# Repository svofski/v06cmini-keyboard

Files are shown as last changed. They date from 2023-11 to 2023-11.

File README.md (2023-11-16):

# A miniature keyboard for Vector-06c

The keyboard is a miniature full-functioning replica of Vector-06c keyboard. Its dimensions are 150x55mm. 
It can be connected as a replacement keyboard to the real Vector-06c, or it can be used as a USB HID keyboard with a Vector-06c emulator or FPGA implementation.
It can also be connected to v06c-esp vector-06c-mini.

The design files comprise 3 parts. 

 1. [Key caps](blender) A high resolution mesh with legend engraving designed in blender
 2. [Bottom PCB](kicad/v06ckeyboard) carries the switches and an optional Pi Pico for connectivity
 3. [Top PCB](kicad/v06ckeyboard) a frame that holds the keycaps in place

This keyboard is very small indeed.

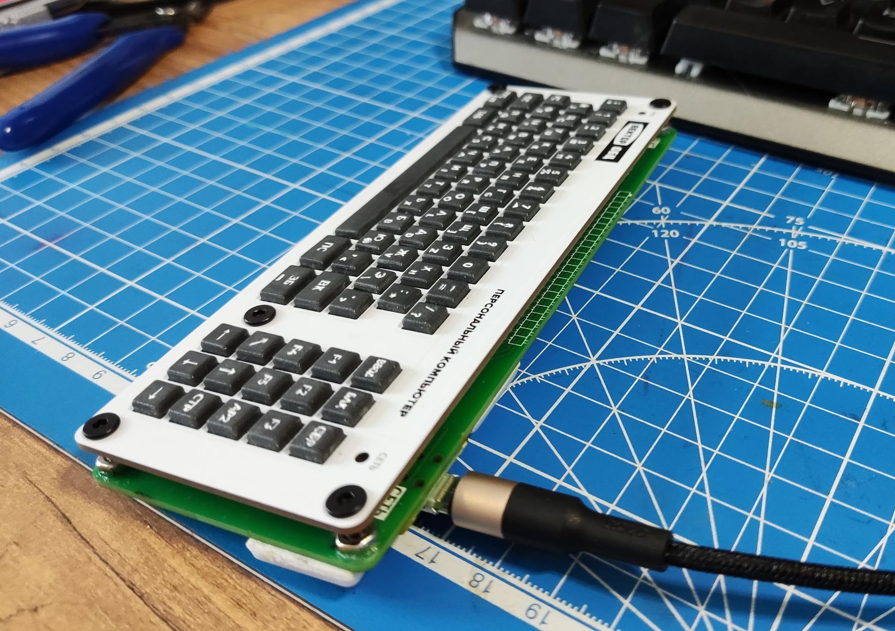
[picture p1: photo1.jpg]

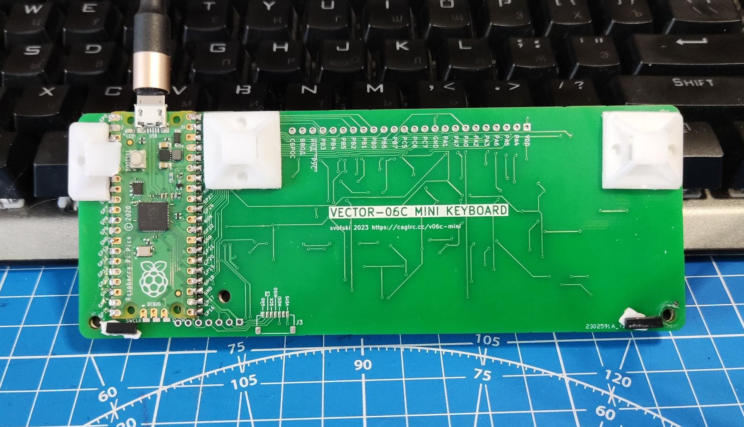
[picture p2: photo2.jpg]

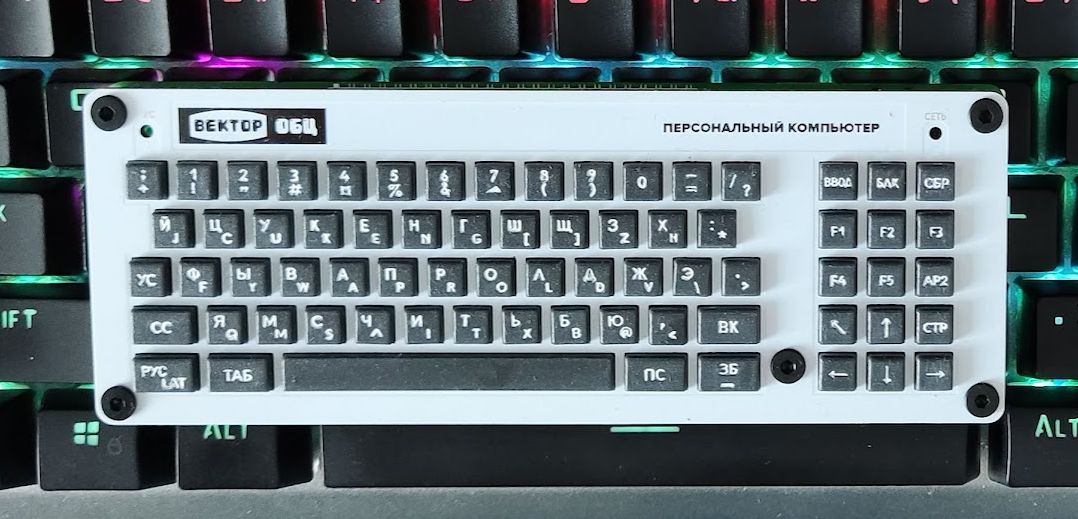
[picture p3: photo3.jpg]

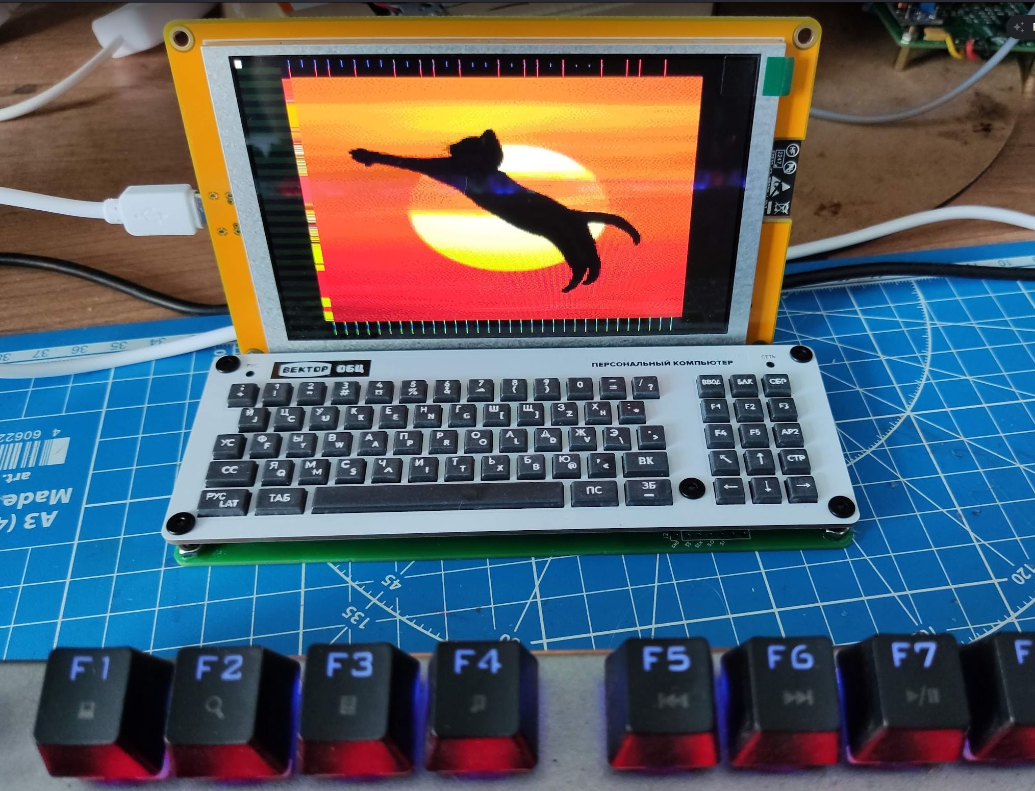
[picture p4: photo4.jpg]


## Firmware

### spislave

[spislave](firmware/spislave) is the main intended use with [v06x-mini](https://github.com/svofski/v06x-tiny).

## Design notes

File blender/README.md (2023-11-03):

# Keycaps design files

keyboard1.blend is the assembly model and keycaps model

Exported .stl is in production files.

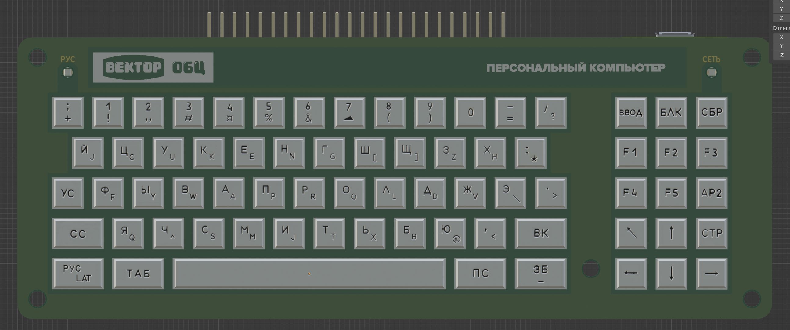
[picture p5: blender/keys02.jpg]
keys02

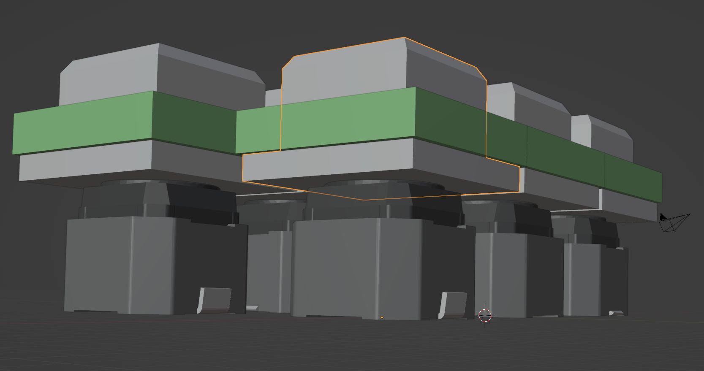
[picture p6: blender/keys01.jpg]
keys01


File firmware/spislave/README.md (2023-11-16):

# v06c-mini keyboard spislave

This is the main mode of this keyboard.
It's an SPI slave for v06x-mini emulator running on esp32-s3.

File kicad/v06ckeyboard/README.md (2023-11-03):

# vector-06c-mini keyboard PCBs

Main PCB and keycaps frame.

Explore using [kicanvas](https://kicanvas.org/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).

[PDF schematic](/kicad/v06ckeyboard/v06c-mini-keyboard.pdf)

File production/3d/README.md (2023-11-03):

[keyboard1.zip](keyboard1.zip) keyboard1.stl suitable for 3D printing

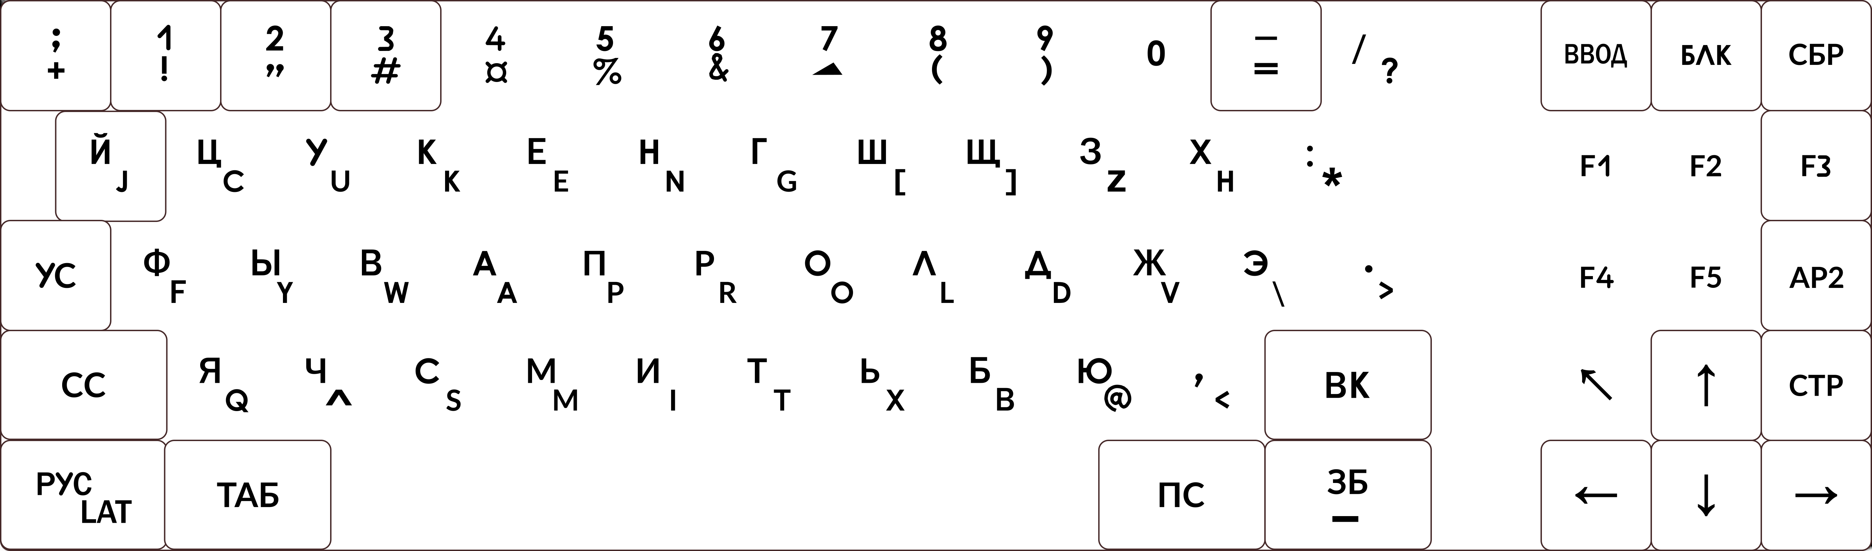
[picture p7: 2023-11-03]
blender/v06c-bump2.png

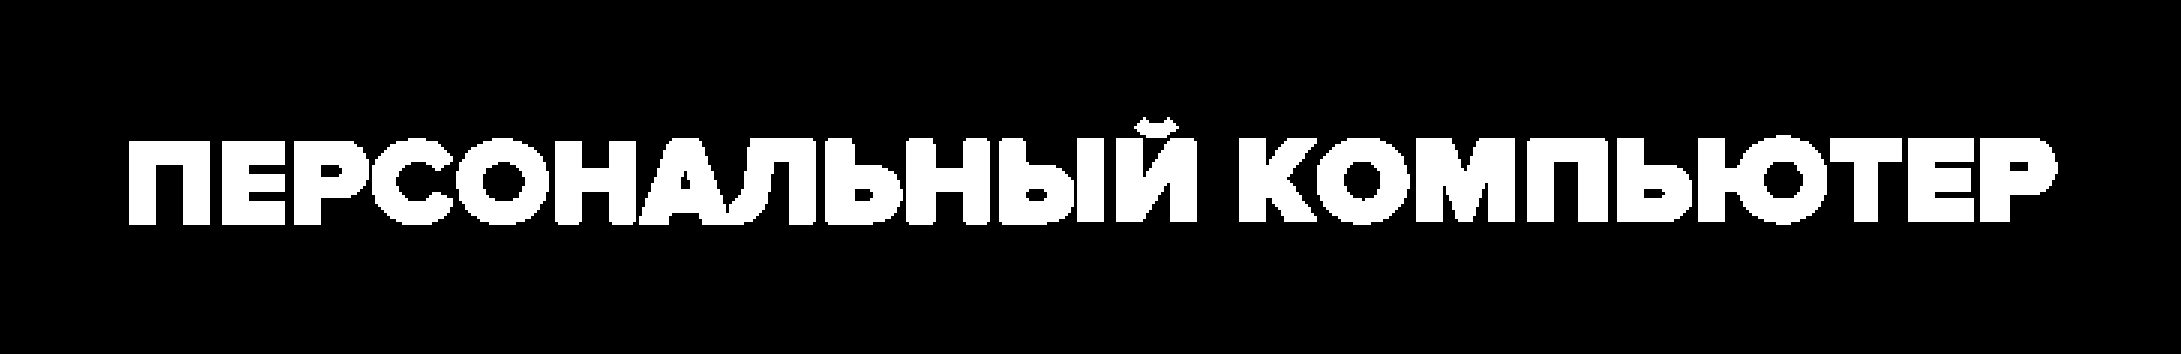
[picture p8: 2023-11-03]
blender/personal.png

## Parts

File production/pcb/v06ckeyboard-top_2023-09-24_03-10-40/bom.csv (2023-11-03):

Designator | Footprint | Quantity | Value | LCSC Part #
H1, H2_3, H2_2, H2, H3, H4, H5 | MountingHole_3.2mm_M3 | 7 | MountingHole
SW100_ВВОД1, SW101_СБР1, SW102_БЛК1, SW104_УС1, SW10_1, SW11_9, SW12_А1, SW13_И1, SW14_Я1, SW15_Ы1, SW16_СТР1, SW18_2, SW19_:1, SW20_Б1, SW21_Й1, SW22_Р1, SW23_З1, SW24_AP2, SW26_3, SW27_;1, SW28_Ц1, SW29_К1, SW2_0, SW30_С1, SW31_Ш1, SW32_F1, SW33_LT1, SW34_4, SW35_,<1, SW36_Д1, SW37_Л1, SW38_Т1, SW39_Э1, SW3_8, SW40_F2, SW41_UP1, SW42_5, SW43_-=1, SW44_E1, SW45_М1, SW46_У1, SW47_Щ1, SW48_F3, SW49_RT1, SW4_Ю1, SW50_6, SW51_.>1, SW52_Ф1, SW53_Н1, SW54_Ж1, SW55_Ч1, SW56_F4, SW57_DN1, SW58_7, SW59_/1, SW5_Х1, SW60_Г1, SW61_О1, SW62_В1, SW64_F5, SW6_П1, SW7_Ь1, SW8_HOME1 | SKPM_Top_Hole | 63 | SKPMAME010 | C115348
SW103_СС1, SW105_РУС/LAT1, SW17_ВК1, SW1_ТАБ1, SW25_ЗБ1, SW9_ПС1 | SKPM_Top_Hole_1.5u | 6 | SKPMAME010 | C115348
SW63_SPC1 | SKPM_Top_Hole_7u | 1 | SKPMAME010 | C115348

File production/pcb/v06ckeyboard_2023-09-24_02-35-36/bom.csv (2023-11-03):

Designator | Footprint | Quantity | Value | LCSC Part #
D1, D2, D3, D4, D5, D6, D7, D8, D9 | D_SOD-323 | 9 | 1N4148WS | C2128
D10 | 0805 | 1 | POWER
D11 | 0805 | 1 | РУС/LAT
H1, H2, H3, H4, H5 | MountingHole_3.2mm_M3 | 5 | MountingHole
J1 | PinHeader_1x24_P2.54mm_Horizontal | 1 | Conn_01x24
J2 | PinHeader_1x07_P2.54mm_Vertical | 1 | SH1.0-7
J3 | JST_SH_SM07B-SRSS-TB_1x07-1MP_P1.00mm_Horizontal | 1 | SH1.0-7
R1, R2, R3, R4, R5, R6, R7, R8 | 0603 | 8 | 2K
R10, R11, R12, R13, R14, R15, R16, R19, R20, R21, R9 | 0603 | 11 | 10K
R17, R18 | 0603 | 2 | 1K
R22, R23 | 0603 | 2 | 430
SW100_ВВОД1, SW101_СБР1, SW102_БЛК1, SW103_СС1, SW104_УС1, SW105_РУС/LAT1, SW10_1, SW11_9, SW12_А1, SW13_И1, SW14_Я1, SW15_Ы1, SW16_СТР1, SW17_ВК1, SW18_2, SW19_:1, SW1_ТАБ1, SW20_Б1, SW21_Й1, SW22_Р1, SW23_З1, SW24_AP2, SW25_ЗБ1, SW26_3, SW27_;1, SW28_Ц1, SW29_К1, SW2_0, SW30_С1, SW31_Ш1, SW32_F1, SW33_LT1, SW34_4, SW35, SW36_Д1, SW37_Л1, SW38_Т1, SW39_Э1, SW3_8, SW40_F2, SW41_UP1, SW42_5, SW43_-=1, SW44_E1, SW45_М1, SW46_У1, SW47_Щ1, SW48_F3, SW49_RT1, SW4_Ю1, SW50_6, SW51, SW52_Ф1, SW53_Н1, SW54_Ж1, SW55_Ч1, SW56_F4, SW57_DN1, SW58_7, SW59_/1, SW5_Х1, SW60_Г1, SW61_О1, SW62_В1, SW63_SPC1, SW63_SPC2, SW64_F5, SW6_П1, SW7_Ь1, SW8_HOME1, SW9_ПС1 | SKPM | 71 | SKPMAME010 | C115348
U1 | RPi_Pico_SMD_TH | 1 | Pico

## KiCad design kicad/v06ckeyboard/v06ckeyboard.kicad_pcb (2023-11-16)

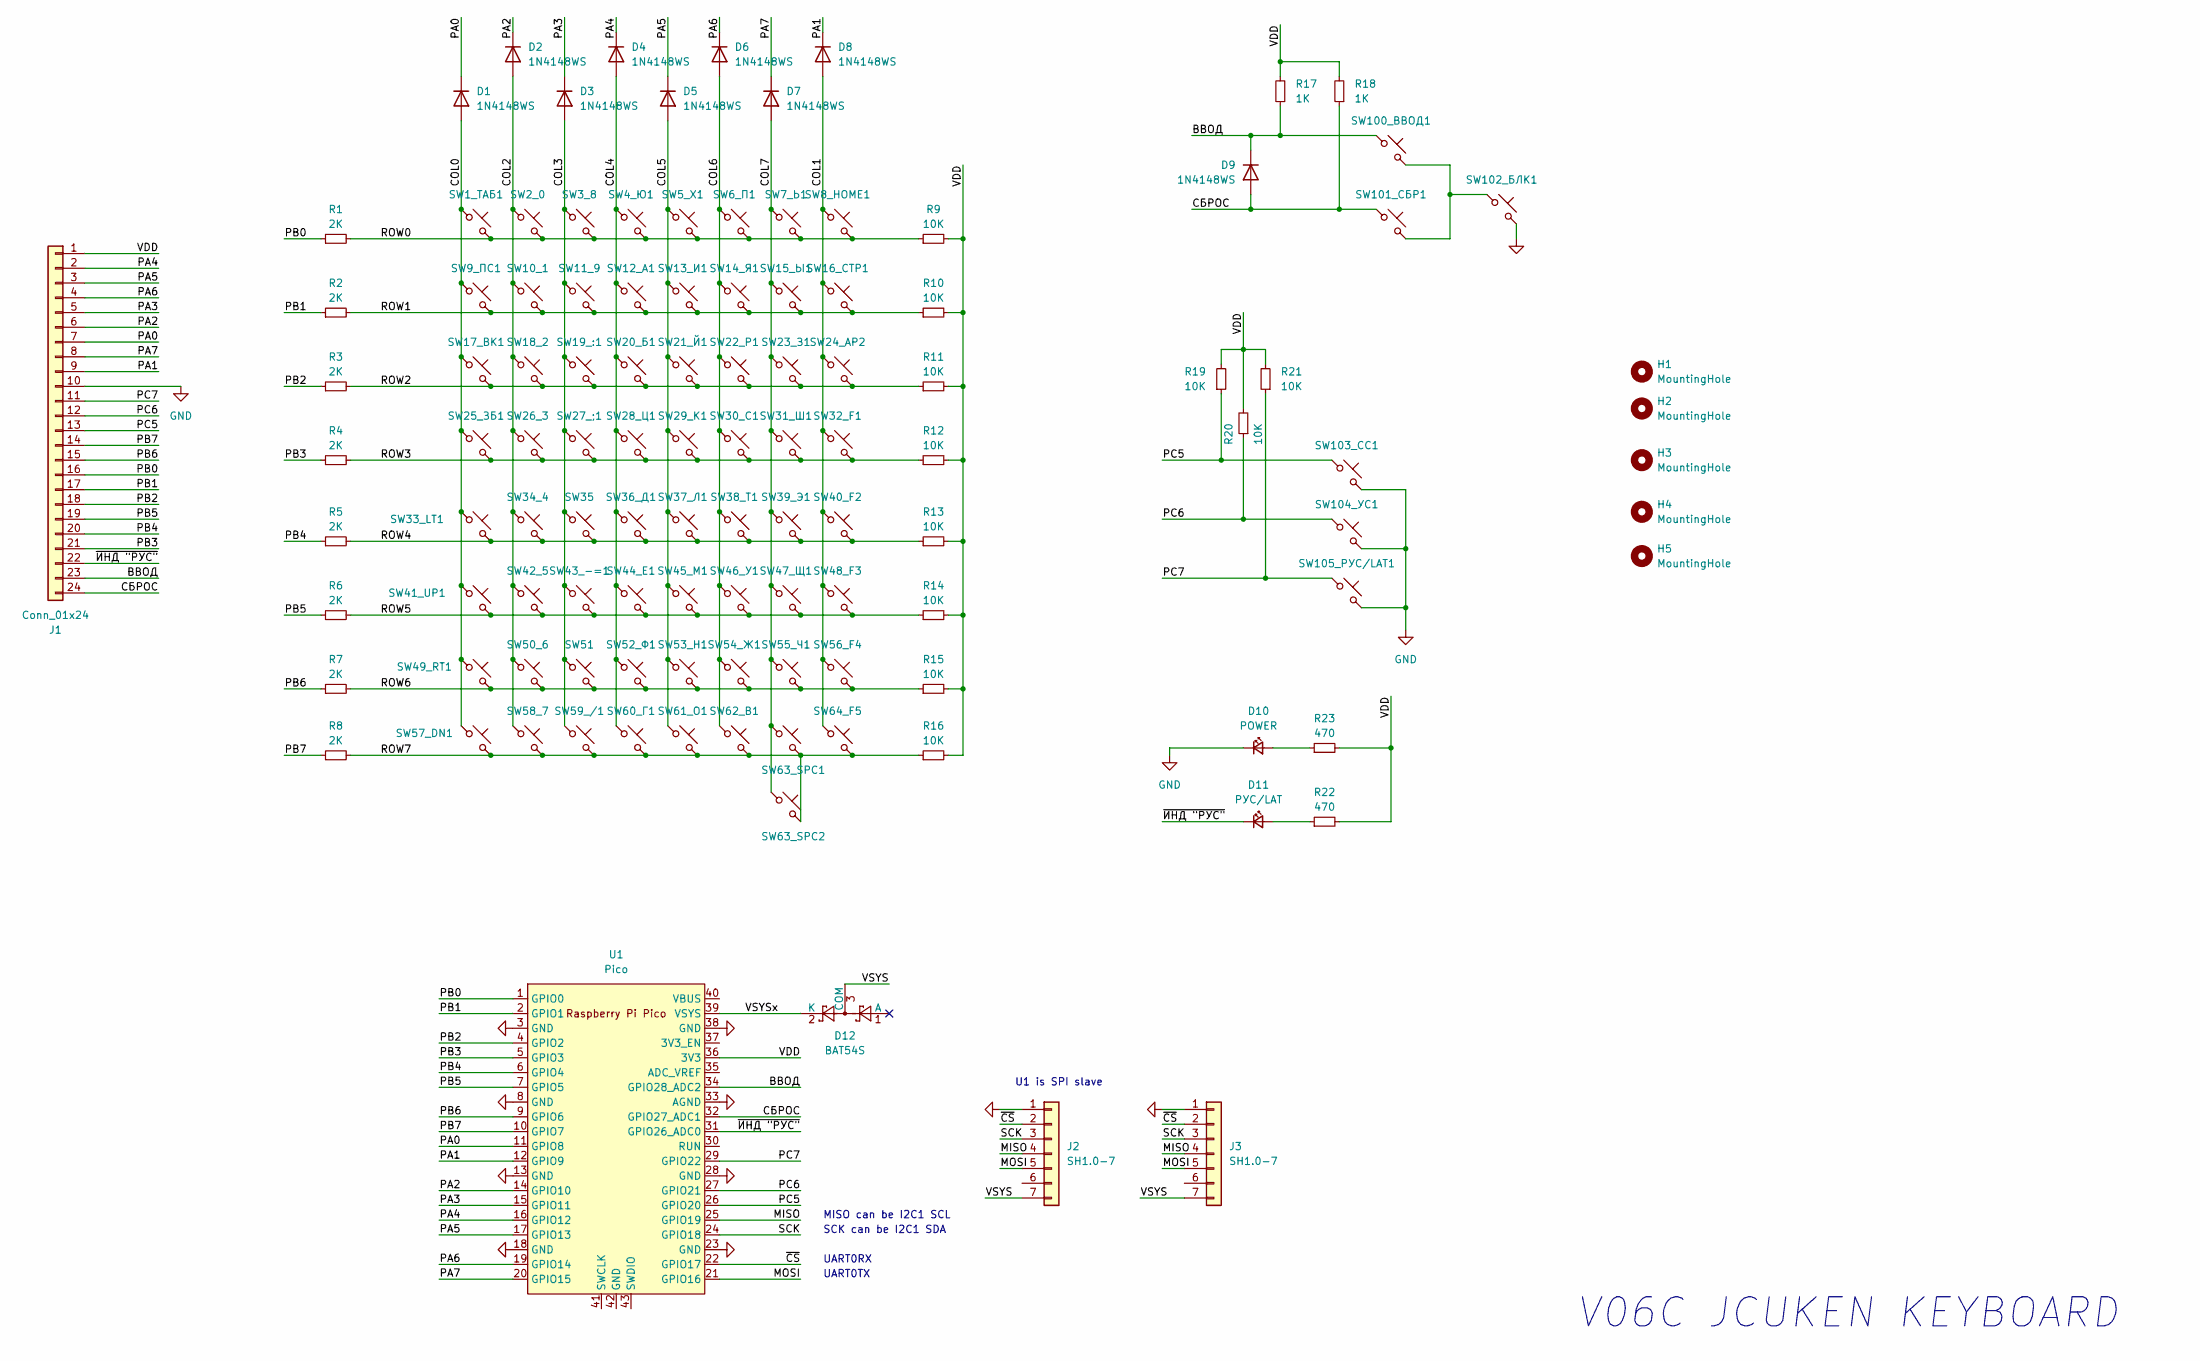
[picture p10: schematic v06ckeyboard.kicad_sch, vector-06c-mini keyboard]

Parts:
D1, D2, D3, D4, D5, D6, D7, D8, D9: 1N4148WS; D_SOD-323; LCSC C2128
D10: POWER; LED_0805_2012Metric
D11: РУС/LAT; LED_0805_2012Metric
D12: BAT54S; SOT-23
H1, H2, H3, H4, H5: MountingHole; MountingHole_3.2mm_M3
J1: Conn_01x24; PinHeader_1x24_P2.54mm_Horizontal
J2: SH1.0-7; PinHeader_1x07_P2.54mm_Vertical
J3: SH1.0-7; JST_SH_SM07B-SRSS-TB_1x07-1MP_P1.00mm_Horizontal
R1, R2, R3, R4, R5, R6, R7, R8: 2K; R_0603_1608Metric
R9, R10, R11, R12, R13, R14, R15, R16, R19, R20, R21: 10K; R_0603_1608Metric
R17, R18: 1K; R_0603_1608Metric
R22, R23: 470; R_0603_1608Metric
SW1_ТАБ1, SW2_0, SW3_8, SW4_Ю1, SW5_Х1, SW6_П1, SW7_Ь1, SW8_HOME1, SW9_ПС1, SW10_1, SW11_9, SW12_А1, SW13_И1, SW14_Я1, SW15_Ы1, SW16_СТР1, SW17_ВК1, SW18_2, SW19_:1, SW20_Б1, SW21_Й1, SW22_Р1, SW23_З1, SW24_AP2, SW25_ЗБ1, SW26_3, SW27_;1, SW28_Ц1, SW29_К1, SW30_С1, SW31_Ш1, SW32_F1, SW33_LT1, SW34_4, SW35, SW36_Д1, SW37_Л1, SW38_Т1, SW39_Э1, SW40_F2, SW41_UP1, SW42_5, SW43_-=1, SW44_E1, SW45_М1, SW46_У1, SW47_Щ1, SW48_F3, SW49_RT1, SW50_6, SW51, SW52_Ф1, SW53_Н1, SW54_Ж1, SW55_Ч1, SW56_F4, SW57_DN1, SW58_7, SW59_/1, SW60_Г1, SW61_О1, SW62_В1, SW63_SPC1, SW63_SPC2, SW64_F5, SW100_ВВОД1, SW101_СБР1, SW102_БЛК1, SW103_СС1, SW104_УС1, SW105_РУС/LAT1: SKPMAME010; SKPM; LCSC C115348
U1: Pico; RPi_Pico_SMD_TH

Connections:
/COL0: D1.2 (A), SW1_ТАБ1.1, SW9_ПС1.1, SW17_ВК1.1, SW25_ЗБ1.1, SW33_LT1.1, SW41_UP1.1, SW49_RT1.1, SW57_DN1.1
/COL1: D8.2 (A), SW8_HOME1.1, SW16_СТР1.1, SW24_AP2.1, SW32_F1.1, SW40_F2.1, SW48_F3.1, SW56_F4.1, SW64_F5.1
/COL2: D2.2 (A), SW2_0.1, SW10_1.1, SW18_2.1, SW26_3.1, SW34_4.1, SW42_5.1, SW50_6.1, SW58_7.1
/COL3: D3.2 (A), SW3_8.1, SW11_9.1, SW19_:1.1, SW27_;1.1, SW35.1, SW43_-=1.1, SW51.1, SW59_/1.1
/COL4: D4.2 (A), SW4_Ю1.1, SW12_А1.1, SW20_Б1.1, SW28_Ц1.1, SW36_Д1.1, SW44_E1.1, SW52_Ф1.1, SW60_Г1.1
/COL5: D5.2 (A), SW5_Х1.1, SW13_И1.1, SW21_Й1.1, SW29_К1.1, SW37_Л1.1, SW45_М1.1, SW53_Н1.1, SW61_О1.1
/COL6: D6.2 (A), SW6_П1.1, SW14_Я1.1, SW22_Р1.1, SW30_С1.1, SW38_Т1.1, SW46_У1.1, SW54_Ж1.1, SW62_В1.1
/COL7: D7.2 (A), SW7_Ь1.1, SW15_Ы1.1, SW23_З1.1, SW31_Ш1.1, SW39_Э1.1, SW47_Щ1.1, SW55_Ч1.1, SW63_SPC1.1, SW63_SPC2.1
/MISO: J2.4, J3.4, U1.25 (GPIO19)
/MOSI: J2.5, J3.5, U1.21 (GPIO16)
/PA0: D1.1 (K), J1.7, U1.11 (GPIO8)
/PA1: D8.1 (K), J1.9, U1.12 (GPIO9)
/PA2: D2.1 (K), J1.6, U1.14 (GPIO10)
/PA3: D3.1 (K), J1.5, U1.15 (GPIO11)
/PA4: D4.1 (K), J1.2, U1.16 (GPIO12)
/PA5: D5.1 (K), J1.3, U1.17 (GPIO13)
/PA6: D6.1 (K), J1.4, U1.19 (GPIO14)
/PA7: D7.1 (K), J1.8, U1.20 (GPIO15)
/PB0: J1.16, R1.1, U1.1 (GPIO0)
/PB1: J1.17, R2.1, U1.2 (GPIO1)
/PB2: J1.18, R3.1, U1.4 (GPIO2)
/PB3: J1.21, R4.1, U1.5 (GPIO3)
/PB4: J1.20, R5.1, U1.6 (GPIO4)
/PB5: J1.19, R6.1, U1.7 (GPIO5)
/PB6: J1.15, R7.1, U1.9 (GPIO6)
/PB7: J1.14, R8.1, U1.10 (GPIO7)
/PC5: J1.13, R19.1, SW103_СС1.1, U1.26 (GPIO20)
/PC6: J1.12, R20.1, SW104_УС1.1, U1.27 (GPIO21)
/PC7: J1.11, R21.1, SW105_РУС/LAT1.1, U1.29 (GPIO22)
/ROW0: R1.2, R9.1, SW1_ТАБ1.2, SW2_0.2, SW3_8.2, SW4_Ю1.2, SW5_Х1.2, SW6_П1.2, SW7_Ь1.2, SW8_HOME1.2
/ROW1: R2.2, R10.1, SW9_ПС1.2, SW10_1.2, SW11_9.2, SW12_А1.2, SW13_И1.2, SW14_Я1.2, SW15_Ы1.2, SW16_СТР1.2
/ROW2: R3.2, R11.1, SW17_ВК1.2, SW18_2.2, SW19_:1.2, SW20_Б1.2, SW21_Й1.2, SW22_Р1.2, SW23_З1.2, SW24_AP2.2
/ROW3: R4.2, R12.1, SW25_ЗБ1.2, SW26_3.2, SW27_;1.2, SW28_Ц1.2, SW29_К1.2, SW30_С1.2, SW31_Ш1.2, SW32_F1.2
/ROW4: R5.2, R13.1, SW33_LT1.2, SW34_4.2, SW35.2, SW36_Д1.2, SW37_Л1.2, SW38_Т1.2, SW39_Э1.2, SW40_F2.2
/ROW5: R6.2, R14.1, SW41_UP1.2, SW42_5.2, SW43_-=1.2, SW44_E1.2, SW45_М1.2, SW46_У1.2, SW47_Щ1.2, SW48_F3.2
/ROW6: R7.2, R15.1, SW49_RT1.2, SW50_6.2, SW51.2, SW52_Ф1.2, SW53_Н1.2, SW54_Ж1.2, SW55_Ч1.2, SW56_F4.2
/ROW7: R8.2, R16.1, SW57_DN1.2, SW58_7.2, SW59_/1.2, SW60_Г1.2, SW61_О1.2, SW62_В1.2, SW63_SPC1.2, SW63_SPC2.2, SW64_F5.2
/SCK: J2.3, J3.3, U1.24 (GPIO18)
/VDD: J1.1, R9.2, R10.2, R11.2, R12.2, R13.2, R14.2, R15.2, R16.2, R17.2, R18.2, R19.2, R20.2, R21.2, R22.2, R23.2, U1.36 (3V3)
/VSYS: D12.3 (COM), J2.7, J3.7
/VSYSx: D12.2 (K), U1.39 (VSYS)
/~CS: J2.2, J3.2, U1.22 (GPIO17)
/~ИНД "РУС": D11.1 (K), J1.22, U1.31 (GPIO26_ADC0)
/ВВОД: D9.1 (K), J1.23, R17.1, SW100_ВВОД1.1, U1.34 (GPIO28_ADC2)
/СБРОС: D9.2 (A), J1.24, R18.1, SW101_СБР1.1, U1.32 (GPIO27_ADC1)
GND: D10.1 (K), J1.10, J2.1, J3.1, SW102_БЛК1.2, SW103_СС1.2, SW104_УС1.2, SW105_РУС/LAT1.2, U1.3 (GND), U1.8 (GND), U1.13 (GND), U1.18 (GND), U1.23 (GND), U1.28 (GND), U1.33 (AGND), U1.38 (GND)
unnamed: D10.2 (A), R23.1
unnamed: D11.2 (A), R22.1
unnamed: SW100_ВВОД1.2, SW101_СБР1.2, SW102_БЛК1.1

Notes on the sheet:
V06C JCUKEN KEYBOARD
UART0TX
MISO can be I2C1 SCL
UART0RX
SCK can be I2C1 SDA
U1 is SPI slave

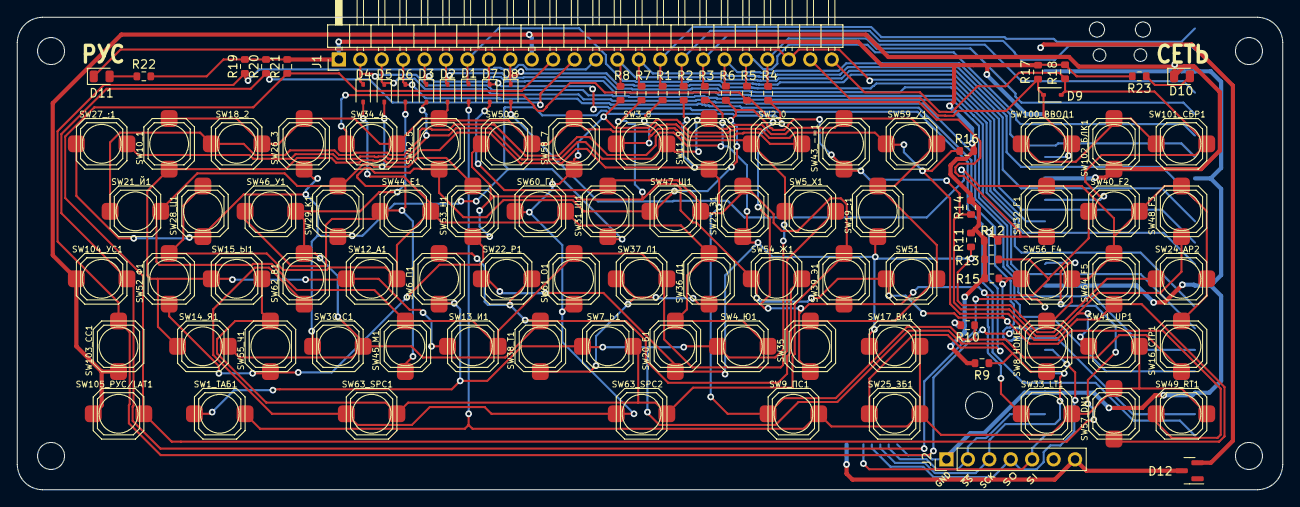
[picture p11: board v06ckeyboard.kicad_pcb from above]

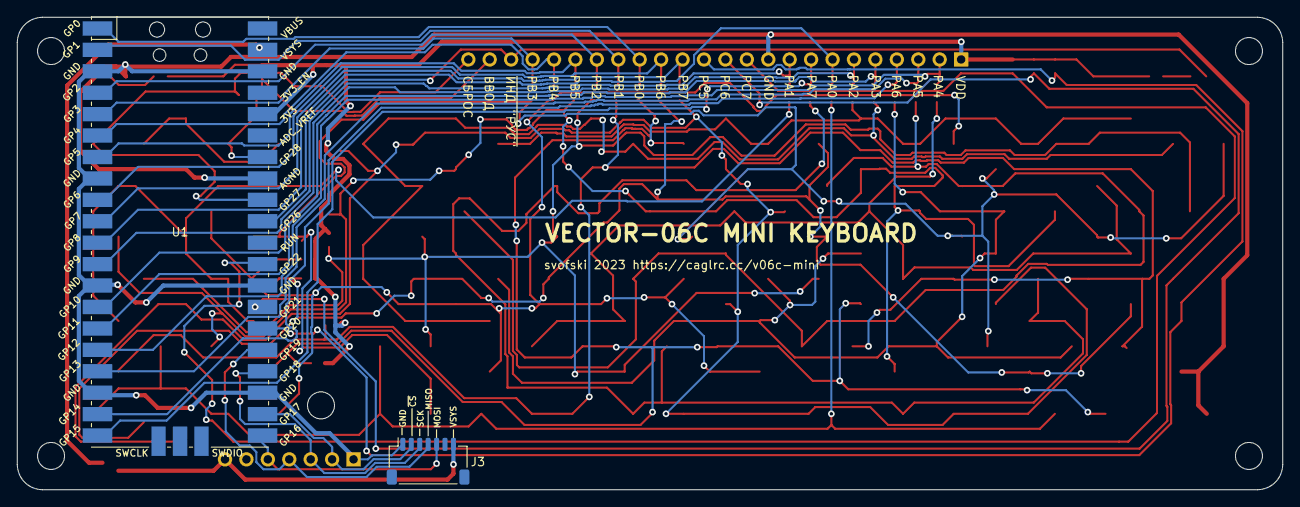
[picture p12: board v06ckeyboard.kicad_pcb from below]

Board: 2 copper layers, 150.0 x 56.0 mm, 115 parts (2 on the bottom side), 49 nets.

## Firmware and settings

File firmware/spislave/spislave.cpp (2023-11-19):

#include <cstdio>
#include <time.h>
#include "pico/stdlib.h"
#include "hardware/spi.h"
#include "pico/multicore.h"

#include <array>

#define SPI_PORT spi0
#define PIN_MOSI 16 // slave input
#define PIN_CS   17 // select (input)
#define PIN_SCK  18 // clock
#define PIN_MISO 19 // slave output

#define MATRIX_ROW_PINS {0, 1, 2, 3, 4, 5, 6, 7}
#define MATRIX_COL_PINS {8, 9, 10, 11, 12, 13, 14, 15}

#define PIN_VVOD    28
#define PIN_SBROS   27

#define MODKEYS_LSB 20
#define PIN_SS      20 // PC5
#define PIN_US      21 // PC6
#define PIN_RUSLAT  22 // PC7
#define PIN_INDRUS  26 // LED output

#define PIN_MODKEYS_MASK  ((1<<(PIN_SS))|(1<<(PIN_US))|(1<<(PIN_RUSLAT))|(1<<(PIN_VVOD))|(1<<(PIN_SBROS)))
#define PIN_INDRUS_MASK (1<<(PIN_INDRUS))

constexpr int row_pins[8] = MATRIX_ROW_PINS;
constexpr int col_pins[8] = MATRIX_COL_PINS;

// modkey bits for portc
constexpr uint8_t PC_MODKEYS_LSB = 5;
constexpr uint8_t PC_BIT_SS = (1<<5);
constexpr uint8_t PC_BIT_US = (1<<6);
constexpr uint8_t PC_BIT_RUSLAT = (1<<7);
constexpr uint8_t PC_MODKEYS_MASK = (PC_BIT_SS | PC_BIT_US | PC_BIT_RUSLAT);

constexpr uint8_t PC_BIT_INDRUS = 3;
constexpr uint8_t PC_BIT_INDRUS_MASK = 1 << PC_BIT_INDRUS;

std::array<uint8_t, 256> debug;
volatile size_t debug_i = 0;
uint8_t rxbyte[4];
uint16_t txbyte;

uint8_t last_cmd = 0;

inline void select_columns(uint8_t w8)
{
    gpio_put_masked(0xff00, w8 << 8);
}

// Boneheaded SPI slave on rp2040 doesn't allow more than one word
// per CS assertion, so we must be smart and push everything in 16-bit frame
//
// The known workaround for this is to use SPI mode 3, but it has drawbacks.
void __time_critical_func(reset_spi)()
{
    spi_init(SPI_PORT, 1000*1000);
    spi_set_format(SPI_PORT, 16, SPI_CPOL_0, SPI_CPHA_0, SPI_MSB_FIRST); 
    spi_set_slave(SPI_PORT, true);
}

// Because rp2040 spi slave is completely broken and it hogs MISO wire
// rely on MISO function switch in the interrupt. this introduces
// a delay between CS and the first bit readable by master.
//
// Luckily Espressif engineers are not forked in the head and there is
// a beautiful feature that lets compensate for for this nonsense,
// spi_device_interface_config_t.cs_ena_pretrans lets CS to set up before
// transmission starts, so we're golden.
void __time_critical_func(spi_exchange)()
{
    // prepare data
    uint32_t all = gpio_get_all();
    uint8_t rows = all & 0xff;

    // RUSLAT|US|SS|000|SBROS|VVOD
    uint8_t modkeys = ((all >> MODKEYS_LSB) & 7) << PC_MODKEYS_LSB;

    modkeys |= (1 & (all >> PIN_VVOD)) << 0;
    modkeys |= (1 & (all >> PIN_SBROS)) << 1;

    // 0: read command
    txbyte = (modkeys << 8) | rows;
    
    spi_get_hw(SPI_PORT)->dr = (uint32_t)txbyte; // prime up tx buffer
                                                 //
    while (!spi_is_readable(SPI_PORT)) 
        tight_loop_contents();
    rxbyte[2] = gpio_get(PIN_CS);

    *(uint16_t *)(&rxbyte[0]) = spi_get_hw(SPI_PORT)->dr;

    last_cmd = rxbyte[1];
    switch (last_cmd) {
        case 0xe5:
            // column select
            select_columns(rxbyte[0]);
            break;
        case 0xe6:
            // send rows (primed)
            break;
        case 0xe7:
            // read modkeys (primed)
            break;
        case 0xe8:
            // set rus/lat
            gpio_put(PIN_INDRUS, (rxbyte[0] >> PC_BIT_INDRUS) & 1);
            break;
    }
    rxbyte[3] = gpio_get(PIN_CS);

    for (size_t i = 0; i < 4; ++i) {
        if (debug_i < debug.size()) {
            debug[debug_i++] = rxbyte[i];
        }
    }
}


// status reg is found once in prepare_soup()
static io_ro_32 *status_reg_cs;

void prepare_soup()
{
    io_irq_ctrl_hw_t *irq_ctrl_base = get_core_num() ? &iobank0_hw->proc1_irq_ctrl : &iobank0_hw->proc0_irq_ctrl;
    status_reg_cs = &irq_ctrl_base->ints[PIN_CS / 8];
}

void __time_critical_func(miso_soup)(void)
{
    // see prepare_soup()
    // io_irq_ctrl_hw_t *irq_ctrl_base = get_core_num() ? &iobank0_hw->proc1_irq_ctrl : &iobank0_hw->proc0_irq_ctrl;
    // io_ro_32 *status_reg_cs = &irq_ctrl_base->ints[PIN_CS / 8];

    uint events = (*status_reg_cs >> 4 * (PIN_CS % 8)) & 0xf;
    if (events) {
        if (events & GPIO_IRQ_EDGE_FALL) {
            gpio_set_function(PIN_MISO, GPIO_FUNC_SPI);
        }
        else if (events & GPIO_IRQ_EDGE_RISE) {
            gpio_set_function(PIN_MISO, GPIO_FUNC_SIO);
        }
        gpio_acknowledge_irq(PIN_CS, events);
    }
}

void __time_critical_func(core1_task)()
{

    reset_spi();

    for(;;) {
        spi_exchange();

        // if we receive strange crap, fix it with a reset
        if (last_cmd != 0xe5 && last_cmd != 0xe6 && last_cmd != 0xe7 && last_cmd != 0xe8) {
            printf("last_cmd=%02x, reset\n", last_cmd);
            reset_spi();
        }
    }
}

int main()
{
    stdio_init_all();
    sleep_us(4000000);
    printf("v06c-mini-keyboard\n");

    // bits 8..15 are columns/outputs
    // bits 0..7 are rows/inputs
    // modkeys are separate inputs
    // indrus is rus led output (0 = on)
    gpio_init_mask(0xffff | PIN_MODKEYS_MASK | PIN_INDRUS_MASK);
    for (int i = 0; i < 8; ++i) {
        gpio_set_dir(i, GPIO_IN);
        gpio_pull_down(i);

        gpio_set_dir(i + 8, GPIO_OUT);
        gpio_put(i + 8, 1);
        gpio_set_drive_strength(i + 8, GPIO_DRIVE_STRENGTH_12MA);
    }

    // modkeys
    gpio_set_dir_in_masked(PIN_MODKEYS_MASK);
    gpio_set_dir(PIN_INDRUS, GPIO_OUT);

    // indrus
    gpio_put(PIN_INDRUS, 1); // off


    spi_init(SPI_PORT, 6000*1000);
    gpio_set_function(PIN_MISO, GPIO_FUNC_SIO);
    //gpio_set_function(PIN_MISO, GPIO_FUNC_SPI);
    gpio_set_function(PIN_CS,   GPIO_FUNC_SPI);
    gpio_set_function(PIN_SCK,  GPIO_FUNC_SPI);
    gpio_set_function(PIN_MOSI, GPIO_FUNC_SPI);


    // manually switch off MISO
    gpio_set_irq_enabled(PIN_CS,  GPIO_IRQ_EDGE_FALL,true);
    gpio_set_irq_enabled(PIN_CS,  GPIO_IRQ_EDGE_RISE, true);
    irq_set_exclusive_handler(IO_IRQ_BANK0, miso_soup);

    prepare_soup();
    irq_set_enabled(IO_IRQ_BANK0, true);

    reset_spi();

    multicore_launch_core1(core1_task);

    // core0 has nothing to do, but we can print useful debug info
    for(;;) {
        if (debug_i == debug.size()) {
            ++debug_i;
            for (int i = 0; i < debug.size(); i += 4) {
                for (int n = 0; n < 4; ++n) {
                    printf("%02x ", debug[i + n]);
                }
                printf("\n");
            }
        }
    }

    return 0;
}

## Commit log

2023-11-03 frist commit
    [bom.csv, designators.csv, positions.csv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]
2023-11-03 added schematic pdf
2023-11-16 readme lala
    [v06ckeyboard.kicad_pcb, v06ckeyboard.kicad_sch]
2023-11-19 rp2040 spi slave is bullshit
